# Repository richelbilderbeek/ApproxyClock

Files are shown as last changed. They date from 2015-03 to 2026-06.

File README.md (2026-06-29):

# Approxyclock

<!-- markdownlint-disable MD013 --><!-- Table rows must be put on one line, hence 80 chars is unavoidable -->






<!-- markdownlint-enable MD013 -->

[Go to our nicely rendered website](https://richelbilderbeek.github.io/approxyclock/).

- [Contributing](docs/CONTRIBUTING.md)

## Files used by continuous integration scripts

<!-- markdownlint-disable MD013 --><!-- Table rows must be put on one line, hence 80 chars is unavoidable -->

Filename                                    |Descriptions
--------------------------------------------|--------------------------------------------------------------------------------------------------------------------------------------
[`mlc_config.json`](mlc_config.json)        |Configuration of the link checker, use `markdown-link-check --config mlc_config.json --quiet docs/**/*.md` to do link checking locally
[`.markdownlint.jsonc`](.markdownlint.jsonc)|Configuration of the Markdown linter, use `markdownlint "**/*.md"` to do markdown linting locally. The name of this file is a default name.
[`.markdownlintignore`](.markdownlintignore)|Files ignored by the Markdown linter, use `markdownlint "**/*.md"` to do markdown linting locally. The name of this file is a default name.

<!-- markdownlint-enable MD013 -->

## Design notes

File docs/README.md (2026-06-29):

# Approxyclock

The Approxyclock is
[one of my machines](https://github.com/richelbilderbeek/Machines)
that uses (the programmable chip of an) Arduino.

It is a clock that gives the correct time, but humans can only approximately estimate it.

- [Photos](photos/README.md)
- [Parts list](parts_list/README.md)
- [Code](src/README.md)
- [Schematic](schematic/README.md)
- [Casing](casing/README.md)
- [FAQ](faq.md)

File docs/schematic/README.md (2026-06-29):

# Schematics

There are two schematics:

## Approxyclock connected to an Arduino

- [Arduino version](approxyclock_with_arduino.fzz)

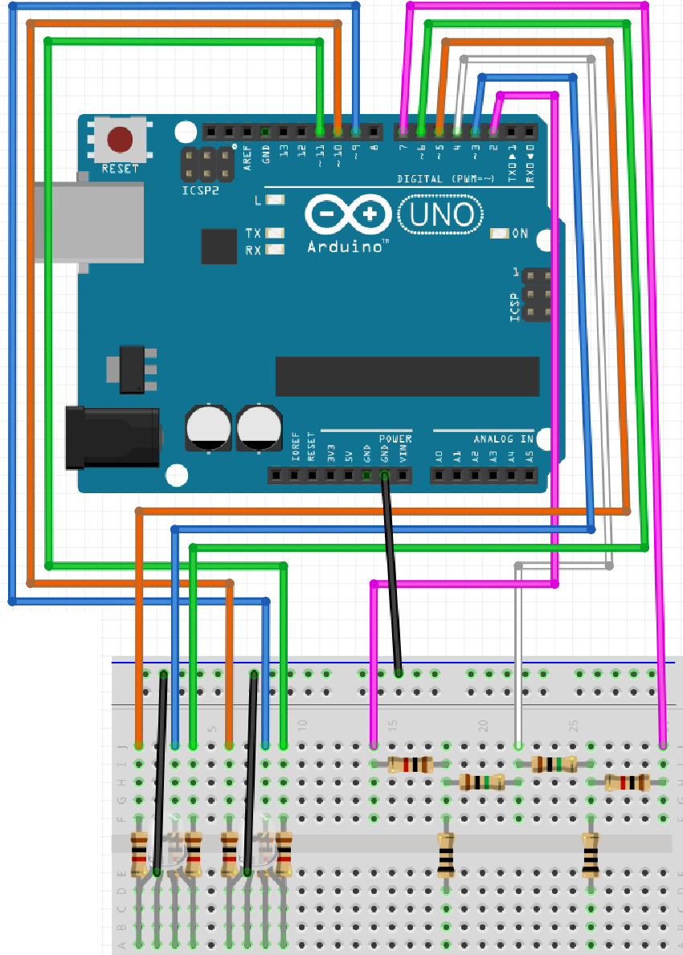
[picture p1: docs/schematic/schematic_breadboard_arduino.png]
Approxyclock connected to an Arduino


## Approxyclock connected to an ATmega328P chip

- [ATmega328P version](approxyclock.fzz)

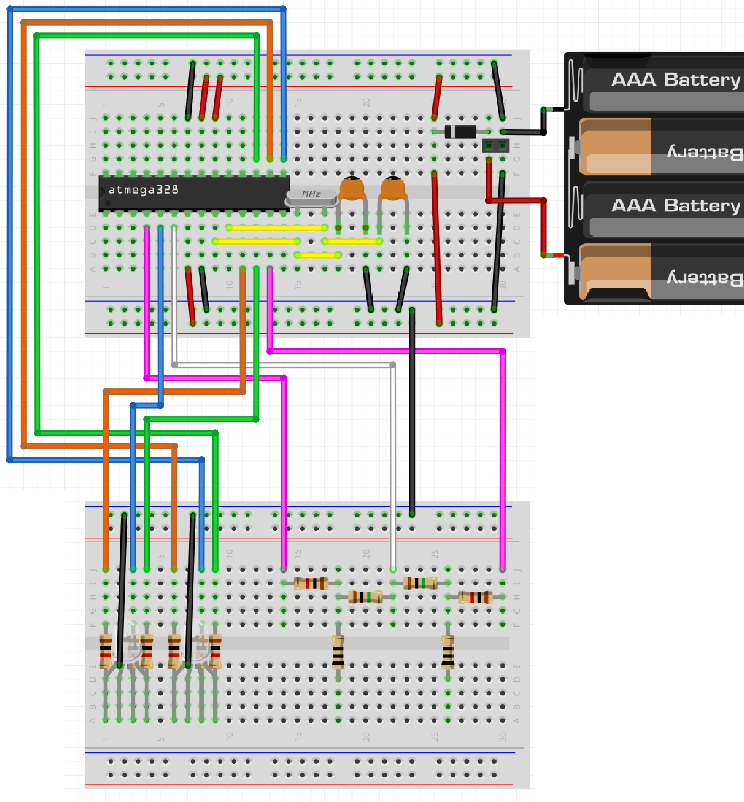
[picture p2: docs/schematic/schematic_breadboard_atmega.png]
Approxyclock connected to an ATmega328P chip


Build the schematic as such,
using the chip with The Minimal Pi Clock
program on it.

??? question "In which orientation must I have the chip?"

    The notch of the chip must be at the left:

    The notch of the chip must be at the left

    > The notch of the chip must be at the left.

??? question "Can you show the wiring of the chip as a table?"

    Yes.

    Here is an equivalent table:

    Pin  |1  |2  |3  |4  |5  |6  |7  |8  |9  |10 |11 |12 |13 |14
    -----|---|---|---|---|---|---|---|---|---|---|---|---|---|---
    Upper|.  |.  |.  |.  |.  |.  |GND|5V |5V |.  |.  |G2 |R2 |B2
    Lower|.  |.  |.  |G1 |R1 |B1 |5V |GND|X1 |X2 |.  |.  |.  |.

    - `GND`: to ground
    - `5V`: to 5 volt
    - `X1`: to a capacitor and crystal
    - `X2`: to (another) capacitor and (the same) crystal
    - `R1`: red LED of first RGB LED
    - `G1`: green LED of first RGB LED
    - `B1`: blue LED of first RGB LED
    - `R2`: red LED of second RGB LED
    - `G2`: green LED of second RGB LED
    - `B2`: blue LED of second RGB LED

??? question "What does '5 Volts in any way' mean?"

    Where the schematic states '5 Volts in any way',
    this means any reasonable way to provide 5 volts
    for the machine.

    In this example, a USB-B female is shown,
    but any USB connector can be used.

??? question "Can I use other electric potenials than 5V?"

    Yes.

    The range of the chip is wider than 5 volts.

Upon powering this, one LED will be dark, but increasingly red every second.
The other LED will be red.

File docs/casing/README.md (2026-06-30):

# Casing

- OpenSCAD file: [`casing.scad`](casing.scad)

I designed the casing in OpenSCAD:

<!--

I used two OpenSCAD libraries:

- [BOSL2](https://github.com/BelfrySCAD/BOSL2): to be able to use
  structures
- [text_on_OpenSCAD](https://github.com/brodykenrick/text_on_OpenSCAD):
  for the text on the machine

-->

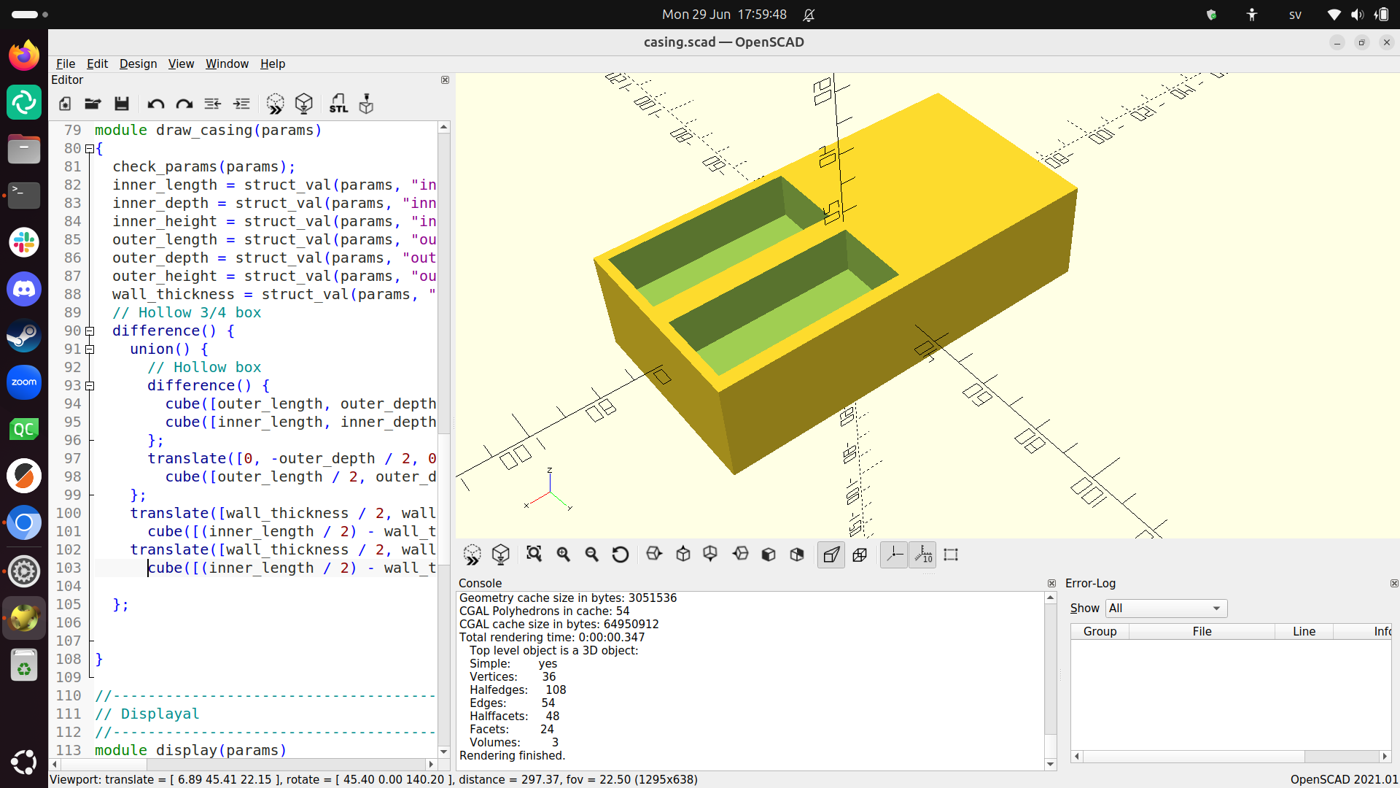
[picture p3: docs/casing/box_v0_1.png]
Current casing


## Box

First, I decided to go with the classical design I used before,
using a box

- OpenSCAD file: [`box.scad`](box.scad)

Approxyclock, box design v0.1

> box design v0.1

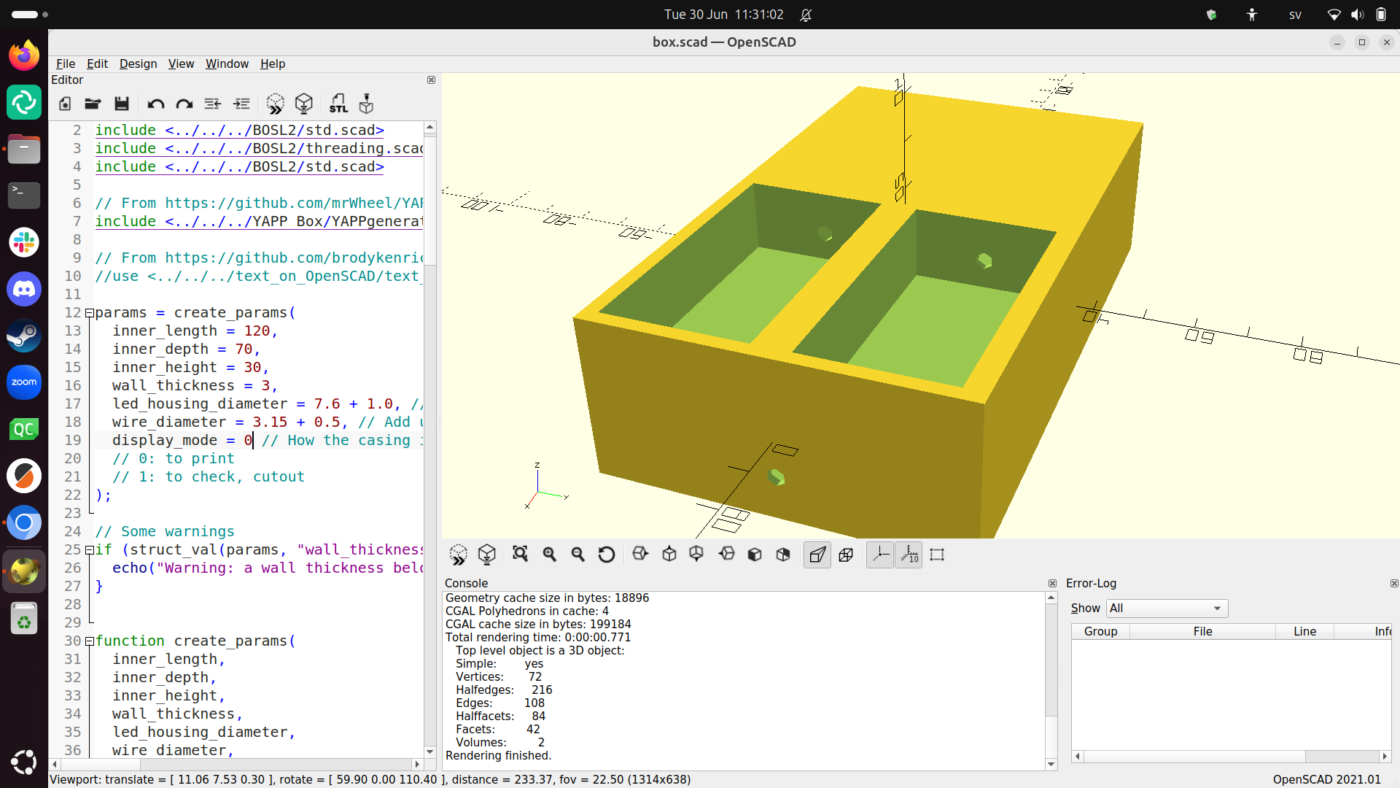
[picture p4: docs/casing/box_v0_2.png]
Approxyclock, box design v0.2


> box design v0.2

Then I realized, that with 3 printing, there is no need to stick to boxes:
I can be more free in the design of my casings: I can make the case round
and use a screw to connect the two parts.

I decided to call my new design the 'Lipstick' design.

## Lipstick

I started with the design of
[The Minimal Pi Clock](https://richelbilderbeek.github.io/minimal_pi_clock/)
and made its spherical design more egg shaped:

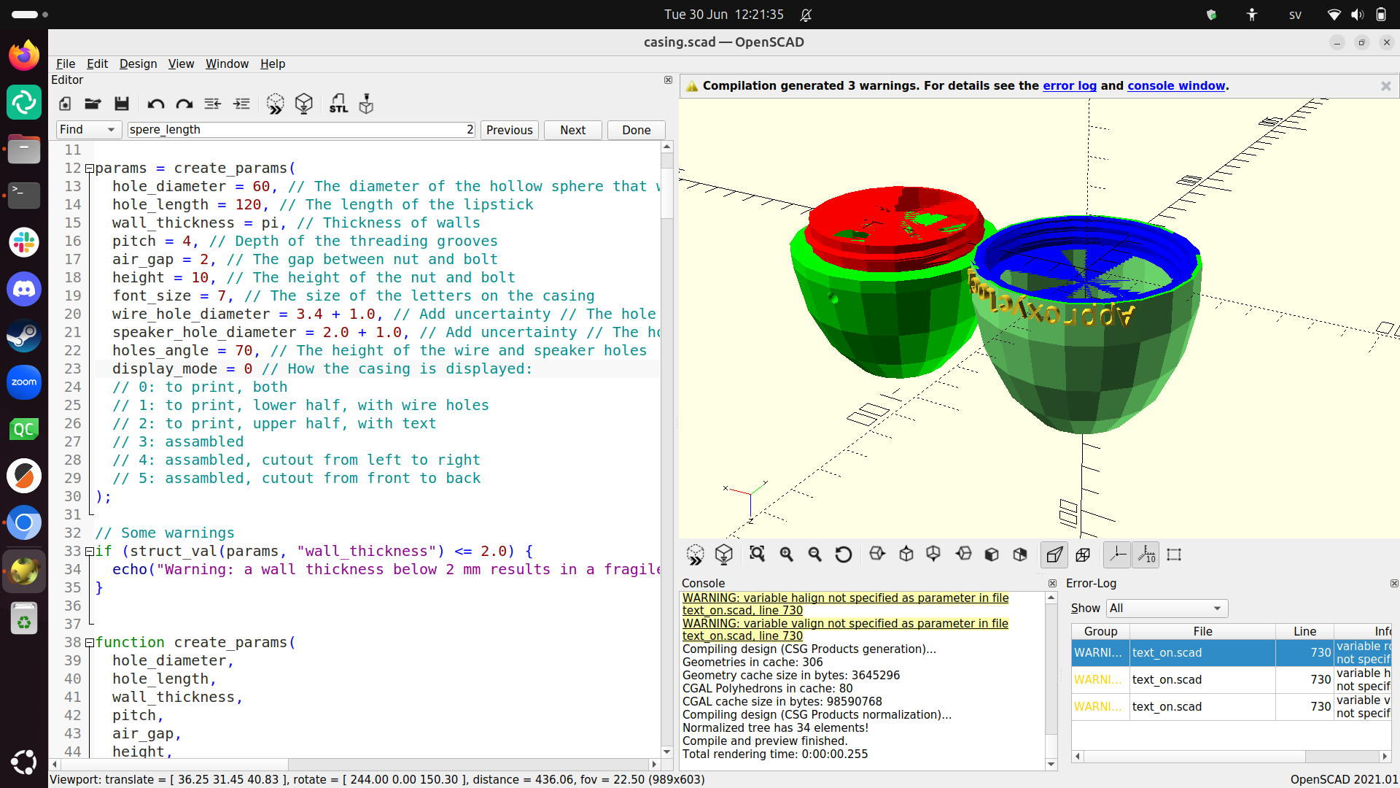
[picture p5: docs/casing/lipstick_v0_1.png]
Approxyclock, lipstick design v0.1


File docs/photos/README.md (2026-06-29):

# Photos

Ordered from new to old

## 2015-04-08: Start with PCB

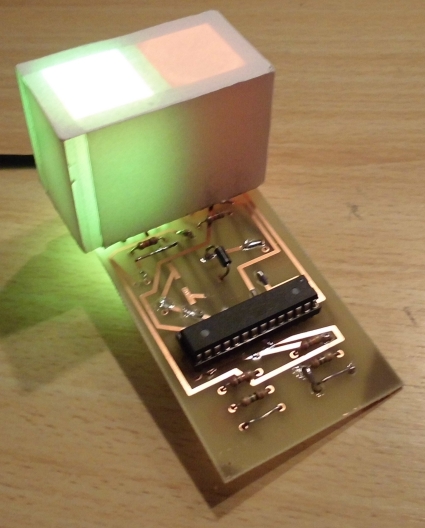
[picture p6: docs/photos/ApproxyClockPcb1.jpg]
ApproxyClock PCB 2015-04-08


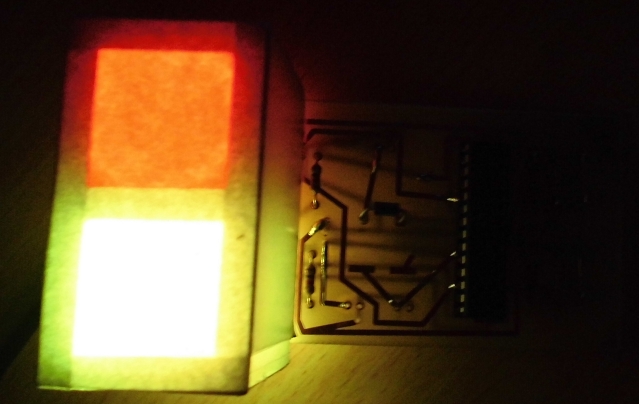
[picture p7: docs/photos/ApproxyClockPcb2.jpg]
ApproxyClock PCB 2015-04-08


## 2015-04-06: Wrapped a paper casing around it

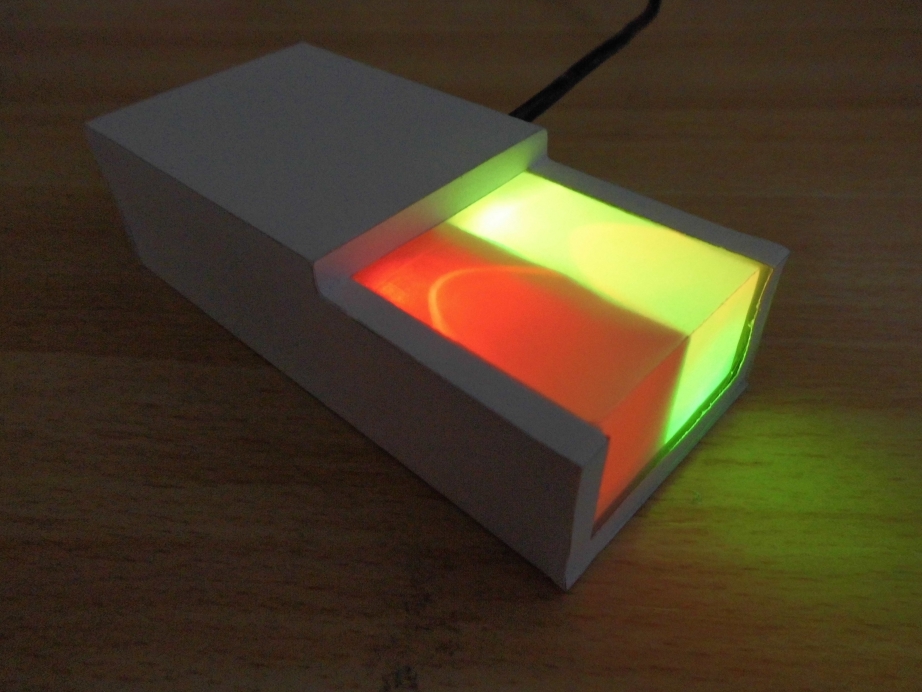
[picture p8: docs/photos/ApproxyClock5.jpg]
ApproxyClock 2015-04-06


## 2015-04-06: Added an extra cut-out

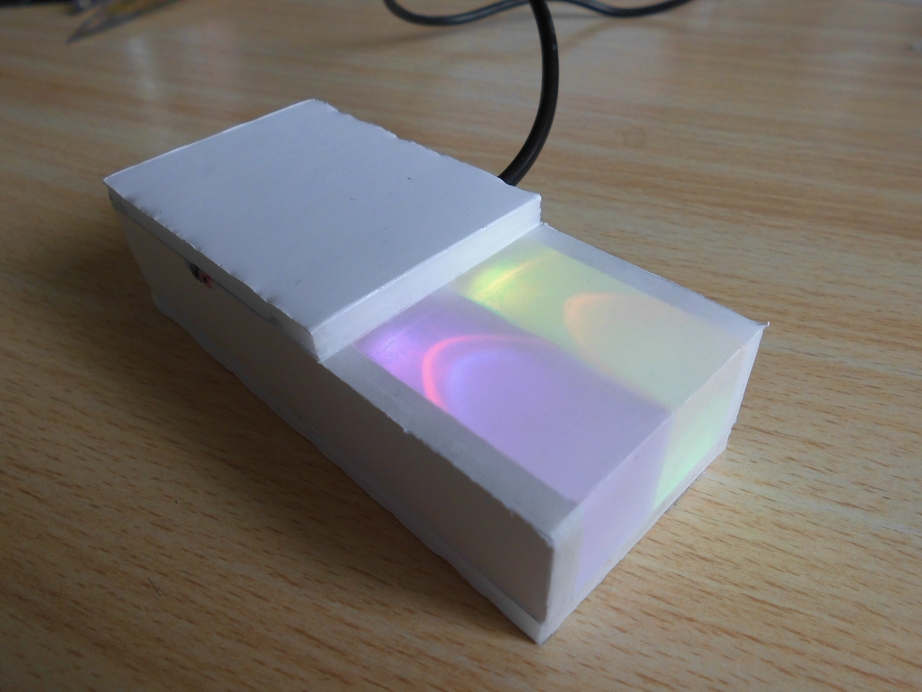
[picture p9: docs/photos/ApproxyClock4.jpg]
ApproxyClock 2015-04-06


## 2015-03-29: Assembled version

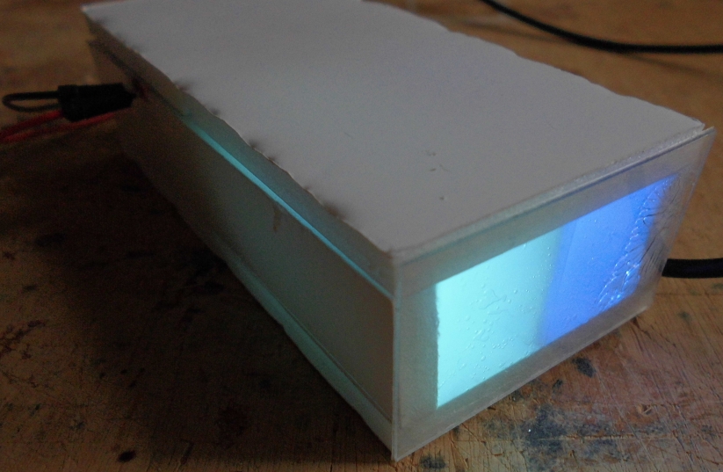
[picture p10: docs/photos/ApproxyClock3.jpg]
ApproxyClock 2015-03-29


## 2015-03-29: Peek into inside before assemblage

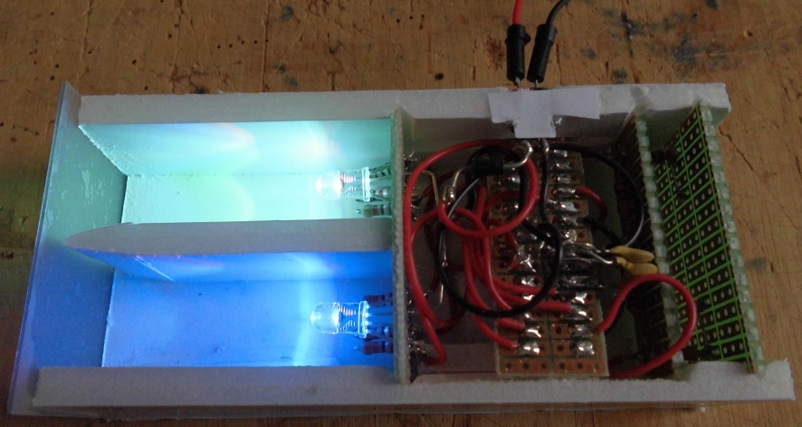
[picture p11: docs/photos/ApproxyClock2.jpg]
ApproxyClock 2015-03-29

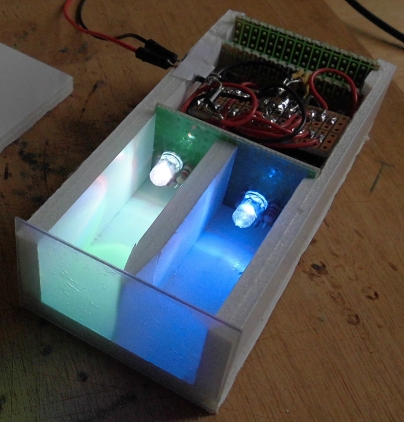
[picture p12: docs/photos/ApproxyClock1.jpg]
ApproxyClock 2015-03-29


## 2015-03-22: Prototype 3: Added touch sensors

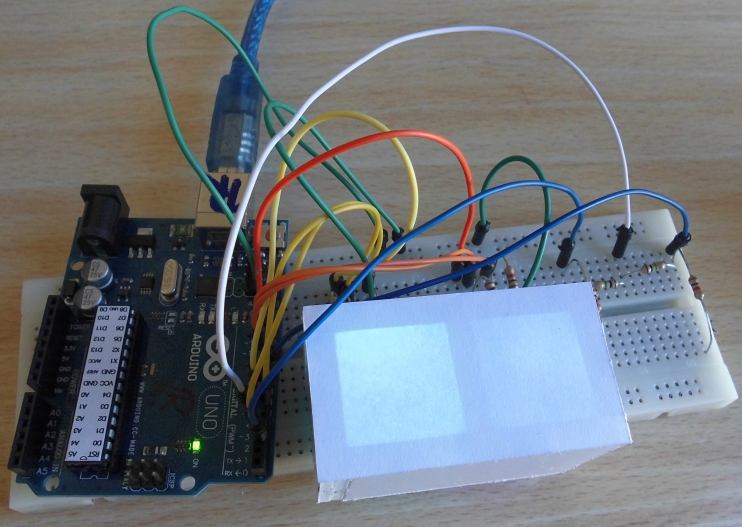
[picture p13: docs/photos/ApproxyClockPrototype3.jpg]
ApproxyClock prototype for 2015-03-22


## 2015-03-22: Prototype 2: Added rainbow time

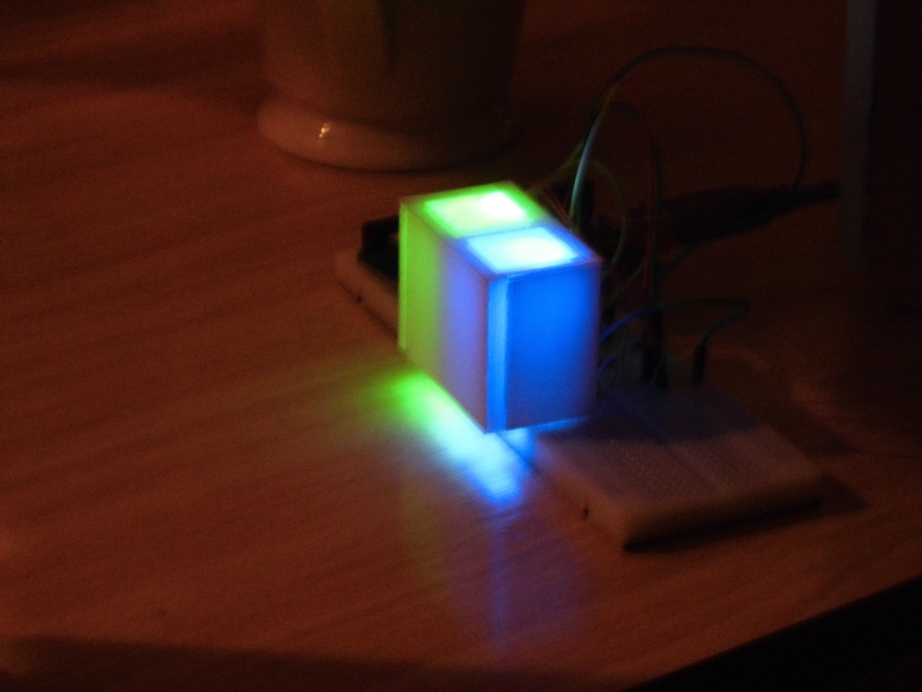
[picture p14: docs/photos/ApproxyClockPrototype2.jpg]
ApproxyClock prototype for 2015-03-22


## 2015-03-21: Prototype 1

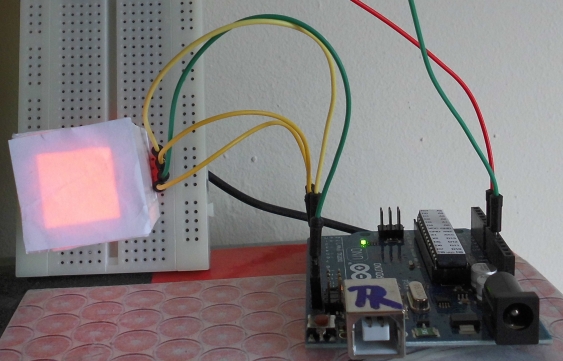
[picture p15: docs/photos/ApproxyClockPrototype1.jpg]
ApproxyClock prototype for 2015-03-21


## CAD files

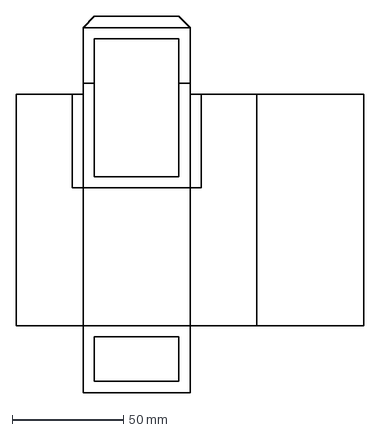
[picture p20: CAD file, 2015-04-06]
docs/casings_history/approxyclock_paper_casing.dxf
156.0 x 169.0 mm

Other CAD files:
docs/casing/box.scad
docs/casing/casing.scad

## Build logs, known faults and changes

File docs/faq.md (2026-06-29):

# Frequently Asked Questions

## How to read the time?

The time is shown in two different modes:

- Classic mode
- Rainbow mode

Classic mode displays the seconds in red, minutes in green, and hours in blue.

- 00:00:00: black
- 00:00:59: full red
- 00:59:00: full green
- 23:00:00: full blue
- 00:59:59: full yellow
- 23:59:00: full cyan
- 23:00:59: full magenta
- 23:59:59: full white

Rainbow mode displays the time according to the colors of the rainbow:

- 00:00: red
- 04:00: yellow
- 08:00: green
- 12:00: cyan
- 16:00: blue
- 20:00: magenta

## Can the ApproxyClock be powered by USB?

Yes. Set `use_usb_for_power` to `true`, which is the case by default.
If this is not the case, the capacitive sensors will work slowly.

## Can the ApproxyClock be powered by a 5V DC adapter?

Yes. Set `use_usb_for_power` to `true`, which is the case by default.
If this is not the case, the capacitive sensors will work slowly.

## Can the ApproxyClock be powered by 4x AAA batteries?

Yes. Set `use_usb_for_power` to `false`.
If this is not the case, the capacitive sensors will not work.

## How expensive is the ApproxyClock?

About ten euros

## Can I make an ApproxyClock myself?

Yes, it is rather easy. All schematics and code are on this GitHub.

## Will you make an ApproxyClock for me?

No. But I can give you two options:

- I can help you build one
- I can find people that like to build one

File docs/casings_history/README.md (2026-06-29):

# Casing's history

Here is the history of [the casing](README.md)
used in this machine.

## Paper

- FreeCAD file: [`approxyclock_paper_casing.dxf`](approxyclock_paper_casing.dxf)

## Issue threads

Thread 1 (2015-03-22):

Create BOM

richelbilderbeek, 2015-03-22:
Create a BOM:

* Arduino, bare bone kit:
 * 1x [Arduino Bare Bones kit](http://www.okaphone.com/artikel.asp?id=476081)
* Or Arduino, loose components (need to upload bootloader):
 * 2x [Capacitor, 47 pF  (22 pF would suffice)](http://www.okaphone.com/artikel.asp?id=478958)
 * 1x [Crystal  (Q16 MHZ HC 49/S), 16 MHz, capacity 32 pF, resonance resistance 50 ohm](http://www.okaphone.com/artikel.asp?id=460438)
 * 1x [Atmega chip](http://www.okaphone.com/artikel.asp?id=468509)

Rest:
* 2x [RGB LED](http://www.okaphone.com/artikel.asp?id=467470)
* 8x 1000 Ohm (brown-black-red-gold) resistance
* 2x 1000000 Ohm (brown-black-green-gold) resistance

Power:
 * If you want to use batteries:
    * 1x [3 AA battery holder](http://www.okaphone.com/artikel.asp?id=1366)
    * 1x [Battery snap clip](http://www.okaphone.com/artikel.asp?id=435836)
 * If you want to use an adapter:
    * 1x 5V DC adapter

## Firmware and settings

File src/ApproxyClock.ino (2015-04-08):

/*

  ApproxyClock with RGB LEDs
  (C) 2015 Richel Bilderbeek

2015-03-21: v.1.0: Initial version
2015-03-22: v.1.1: use of Time library
2015-03-22: v.1.2: added parallel display of rainbow format
2015-03-22: v.1.3: can set the (approximate) time using capacitive sensors
2015-03-22: v.1.4: show rainbow time while setting the clock
2015-03-22: v.1.5: bugfix in rainbow time
2015-04-01: v.1.6: capacitive sensor threshold is changed according to use of battery or USB/adapter

Original RGB LEDs:
    ___
   /   \
  |     |
  +-+-+-+
  | | | |
  | | | |
  | | |
    |
    
  1 2 3 4

1: Blue, connect with resistance of 1000 (brown-black-red-gold) to Arduino pin 3 (note: must be a PWM pin)
2: GND
3: Red, connect with resistance of 1000 (brown-black-red-gold) to Arduino pin 5 (note: must be a PWM pin)
4: Green, connect with resistance of 2200 (red-red-red-gold) to Arduino pin 6 (note: must be a PWM pin)

Rainbow RGB LEDs:
    ___
   /   \
  |     |
  +-+-+-+
  | | | |
  | | | |
  | | |
    |
    
  1 2 3 4

1: Blue, connect with resistance of 1000 (brown-black-red-gold) to Arduino pin 9 (note: must be a PWM pin)
2: GND
3: Red, connect with resistance of 1000 (brown-black-red-gold) to Arduino pin 10 (note: must be a PWM pin)
4: Green, connect with resistance of 2200 (red-red-red-gold) to Arduino pin 11 (note: must be a PWM pin)

Left capacitive sensor:

       +--------+     +--------+  
   2 --+   RS   +--+--+   RH   |-- 4
       +--------+  |  +--------+
                   |
                   X

  2: sensor pin
  4: helper pin
  RH: 'resistance helper', resistance of at least 1 Mega-Ohm (brown-black-green-gold)
  RS: 'resistance sensor', resistance of 1 kOhm (brown-black-red-gold)
  X: place to touch wire

Right capacitive sensor:

       +--------+     +--------+  
   7 --+   RS   +--+--+   RH   |-- 4
       +--------+  |  +--------+
                   |
                   X

  7: sensor pin
  4: helper pin
  RH: 'resistance helper', resistance of at least 1 Mega-Ohm (brown-black-green-gold)
  RS: 'resistance sensor', resistance of 1 kOhm (brown-black-red-gold)
  X: place to touch wire

*/

//if NDEBUG is #defined, this is a release version
#define NDEBUG

#include <CapacitiveSensor.h>
#include <Time.h>

//User setup

//If you use an USB cable or adapter, set use_usb_for_power to true
//If you use 4x AAA batteries, set use_usb_for_power to false
const bool use_usb_for_power = false;

//End of user setup

const int blue_original_pin = 3;
const int red_original_pin = 5;
const int green_original_pin = 6;

const int blue_rainbow_pin = 9;
const int red_rainbow_pin = 10;
const int green_rainbow_pin = 11;

/* When using the PCB print:
const int blue_original_pin  = 6;
const int red_original_pin   = 3;
const int green_original_pin = 5;

const int blue_rainbow_pin  = 11;
const int red_rainbow_pin   = 9;
const int green_rainbow_pin = 10;
*/

const int pin_sensor1 =  2;
const int pin_helper1 =  4;
CapacitiveSensor sensor1 
  = CapacitiveSensor(pin_helper1,pin_sensor1);        

const int pin_sensor2 =  7;
const int pin_helper2 =  4;
CapacitiveSensor sensor2 
  = CapacitiveSensor(pin_helper2,pin_sensor2);        


const int error_pin = 13;

//Threshold for capacitive sensor, which determines the sensitivity of the sensors
// - too low: the program will think more often there is a touch, possibly even when you do not touch
// - too high: the program will think less often there is a touch, possibly even when you do touch
//Some guidelines I use:
// - Using an adapter or USB: 200
// - Using 4x 1.5 AAA battery: 50
const int threshold_usb = 200;
const int threshold_batteries = 50;

void OnError(const String& error_message)

{
  Serial.print("ERROR: ");  
  Serial.println(error_message);  
  while (1)
  {
    //Blink LED
    digitalWrite(error_pin,!digitalRead(error_pin));
    //Write to serial
    delay(1000);
  }
}

void TestTime()
{
  //  setTime(hours, minutes, seconds, days, months, years);
  const int hours = 11;
  const int minutes = 22;
  const int seconds = 33;
  const int days = 0;
  const int months = 0;
  const int years = 0;
  setTime(hours, minutes, seconds, days, months, years);
  if (hour() != hours) { OnError("TestTime #1"); }
  if (minute() != minutes) { OnError("TestTime #1"); }
  if (second() != seconds) { OnError("TestTime #1"); }
  setTime(0,0,0,0,0,0);
}

void setup()
{
  pinMode(red_original_pin,OUTPUT);
  pinMode(green_original_pin,OUTPUT);
  pinMode(blue_original_pin,OUTPUT);
  pinMode(red_rainbow_pin,OUTPUT);
  pinMode(green_rainbow_pin,OUTPUT);
  pinMode(blue_rainbow_pin,OUTPUT);
  pinMode(error_pin,OUTPUT);
  Serial.begin(9600); //Cannot be used: chip is used stand-alone
  #ifndef NDEBUG
  Serial.println("ApproxyClock v. 1.5 (debug version)");
  #else //NDEBUG
  Serial.println("ApproxyClock v. 1.5 (release version)");
  #endif //NDEBUG
  TestTime();
}

//0 = 00 : none pressed
//1 = 01 : right pressed
//2 = 10 : left pressed
//3 = 11 : both pressed
const int state_no_sensor_pressed    = 0; //00
const int state_right_sensor_pressed = 1; //01
const int state_left_sensor_pressed  = 2; //10
const int state_both_sensors_pressed = 3; //11

///Obtain the current state of both capacitive sensors
int GetSensors()
{
  //The higher 'samples' is set, the more accurate the sensors measure
  const int samples = 30;
  //Measure the capacitive sensors
  const int r1 = sensor1.capacitiveSensor(samples);
  const int r2 = sensor2.capacitiveSensor(samples);
  //The threshold value, which determines the sensitivity of the sensors
  // - too low: the program will think more often there is a touch, possibly even when you do not touch
  // - too high: the program will think less often there is a touch, possibly even when you do touch
  //Some guidelines I use:
  // - Using an adapter or USB: 200
  // - Using 4x 1.5 AAA battery: 50
  const int threshold = use_usb_for_power ? threshold_usb : threshold_batteries;
  const int state =  (r1 >= threshold ? 2 : 0) + (r2 >= threshold ? 1 : 0);
  return state;
}

/// User can choose to set the hours
/// - left sensor: cancel
/// - right sensor: set hours
void SetHours()
{
  Serial.println("Setting hours");
  int h = hour();
  bool accept = false; //Accept editing the hours
  while (1)
  {
    //The line below is commented out, because the user must first accept to edit it
    //ShowTimeOriginal(0,0,h); //secs, mins, hours
    const int sensor_state = GetSensors();
    if (sensor_state == state_left_sensor_pressed)
    {
      //  setTime(hours, minutes, seconds, days, months, years);
      setTime(h,minute(),second(),0,0,0);
      break; 
    }
    if (sensor_state == state_right_sensor_pressed)
    {
      if (accept) { h = (h + 1) % 24; }
      else { accept = true; }
    }
    //This line is put here, because the user must first accept to edit the time
    ShowTimeOriginal(0,0,h); //secs, mins, hours
    ShowTimeRainbow(second(),minute(),h); //secs, mins, hours
    delay(100);
  }
  #ifndef NDEBUG
  if (h <  0) { OnError("h <  0, h = " + String(h)); }
  if (h > 23) { OnError("h > 23, h = " + String(h)); }
  #endif // NDEBUG
}

/// User can choose to set the minutes
/// - left sensor: cancel
/// - right sensor: set minutes
void SetMinutes()
{
  Serial.println("Setting minutes");
  int m = minute();
  bool accept = false; //Accept editing the minutes
  while (1)
  {
    ShowTimeOriginal(0,m,0); //secs, mins, hours
    ShowTimeRainbow(second(),m,hour()); //secs, mins, hours
    const int sensor_state = GetSensors();
    if (sensor_state == state_left_sensor_pressed)
    {
      //  setTime(hours, minutes, seconds, days, months, years);
      setTime(hour(),m,second(),0,0,0);
      break; 
    }
    if (sensor_state == state_right_sensor_pressed)
    {
      if (accept) { m = (m + 1) % 60; }
      else { accept = true; }
    }
    delay(100);
  }
  #ifndef NDEBUG
  if (m <  0) { OnError("m <  0, h = " + String(m)); }
  if (m > 59) { OnError("m > 59, h = " + String(m)); }
  #endif // NDEBUG
}

/// User can choose to set the seconds
/// - left sensor: cancel
/// - right sensor: set seconds
void SetSeconds()
{
  Serial.println("Setting seconds");
  int s = second();
  bool accept = false; //Accept editing the seconds
  while (1)
  {
    ShowTimeOriginal(s,0,0); //secs, mins, hours
    ShowTimeRainbow(s,minute(),hour()); //secs, mins, hours
    const int sensor_state = GetSensors();
    if (sensor_state == state_left_sensor_pressed)
    {
      //  setTime(hours, minutes, seconds, days, months, years);
      setTime(hour(),minute(),s,0,0,0);
      break; 
    }
    if (sensor_state == state_right_sensor_pressed)
    {
      if (accept) { s = (s + 1) % 60; }
      else { accept = true; }
    }
    delay(100);
  }
  #ifndef NDEBUG
  if (s <  0) { OnError("s <  0, h = " + String(s)); }
  if (s > 59) { OnError("s > 59, h = " + String(s)); }
  #endif // NDEBUG
}


/// User can choose to set the time
/// - left sensor: select hours, minutes, seconds, cancel
/// - right sensor: change hours, minutes, seconds
void SetTime()
{
  Serial.println("Setting time");
  //The user can choose to set the hours, make the hours blink
  while (1)
  {
    //Blink hours
    ShowTimeOriginal(0,0,23); //Secs, mins, hours
    delay(100);
    ShowTimeOriginal(0,0,0); //Secs, mins, hours
    delay(100);
    const int sensor_state = GetSensors();
    if (sensor_state == state_right_sensor_pressed)
    {
      SetHours();
      break;
    }
    if (sensor_state == state_left_sensor_pressed)
    {
      break; 
    }
  }  
  //The user can choose to set the minutes, make the minutes blink
  while (1)
  {
    //Blink minutes
    ShowTimeOriginal(0,59,0); //Secs, mins, hours
    delay(100);
    ShowTimeOriginal(0,0,0); //Secs, mins, hours
    delay(100);
    const int sensor_state = GetSensors();
    if (sensor_state == state_right_sensor_pressed)
    {
      SetMinutes();
      break;
    }
    if (sensor_state == state_left_sensor_pressed)
    {
      break; 
    }
  }  
  //The user can choose to set the seconds, make the seconds blink
  while (1)
  {
    //Blink second
    ShowTimeOriginal(59,0,0); //Secs, mins, hours
    delay(100);
    ShowTimeOriginal(0,0,0); //Secs, mins, hours
    delay(100);
    const int sensor_state = GetSensors();
    if (sensor_state == state_right_sensor_pressed)
    {
      SetSeconds();
      break;
    }
    if (sensor_state == state_left_sensor_pressed)
    {
      break; 
    }
  }  
}

void SetTimeFromSerial()
{
  //Serial.println("Start of SetTimeFromSerial");
  const int  h  = Serial.available() ? Serial.parseInt() : -1;
  delay(10);
  const char c1 = Serial.available() ? Serial.read() : '0';
  delay(10);
  const int  m  = Serial.available() ? Serial.parseInt() : -1;
  delay(10);
  const char c2 = Serial.available() ? Serial.read() : '0';
  delay(10);
  const int  s  = Serial.available() ? Serial.parseInt() : -1;
  delay(10);
  const String used = String(h) + String(c1) + String(m) + String(c2) + String(s);
  if (h == -1) 
  {
    Serial.println(String("No hours, use e.g. '12:34:56' (used '") + used + String("')"));
    return;
  }
  if (c1 == '0') 
  {
    Serial.println("No first seperator, use e.g. '12:34:56' (used '" + used + "')");
    return;
  }
  if (m == -1) 
  {
    Serial.println("No minutes, use e.g. '12:34:56' (used '" + used + "')");
    return;
  }
  if (c2 == '0') 
  {
    Serial.println("No second seperator, use e.g. '12:34:56'");
    return;
  }
  if (s == -1) 
  {
    Serial.println("No seconds, use e.g. '12:34:56'");
    return;
  }
  if (h < 0 || h > 23)
  {
    Serial.println("Hours must be in range [0,23]");
    return;
  }
  if (m < 0 || h > 59)
  {
    Serial.println("Minutes must be in range [0,59]");
    return;
  }
  if (s < 0 || s > 59)
  {
    Serial.println("Seconds must be in range [0,59]");
    return;
  }
  setTime(h,m,s,0,0,0); 
}

void loop() 
{
  int last_sec = -1; //The previous second, used to detect a change in time, to be sent to serial monitor
  while (1)
  {
    //Respond to touches
    const int sensors_state = GetSensors();
    if (sensors_state == state_left_sensor_pressed) { SetTime(); delay(100); }

    if (Serial.available())
    {
      delay(100);
      SetTimeFromSerial();  
    }
    //Show the time
    const int s = second();
    const int m = minute();
    const int h = hour();

    if (last_sec == s) 
    {
      continue;
    }

    last_sec = s;
    ShowTimeOriginal(s,m,h);
    ShowTimeRainbow(s,m,h);

    //if (sensors_state == state_right_sensor_pressed) 
    { 
      const String time_now = String(h) + ":" + String(m) + ":" + String(s);
      Serial.println(time_now);
      delay(100);
    }
  }
}

///Show the time on all RGB LEDs
void ShowTimeOriginal(const int secs, const int mins, const int hours)
{
  #ifndef NDEBUG
  if (hours <  0) { OnError("ShowTime: hours <  0, hours = " + String(hours)); }
  if (hours > 23) { OnError("ShowTime: hours > 23, hours = " + String(hours)); }
  if (mins <  0) { OnError("ShowTime: mins <  0, mins = " + String(mins)); }
  if (mins > 59) { OnError("ShowTime: mins > 59, mins = " + String(mins)); }
  if (secs <  0) { OnError("ShowTime: secs <  0, secs = " + String(secs)); }
  if (secs > 59) { OnError("ShowTime: secs > 59, secs = " + String(secs)); }
  #endif // NDEBUG
  const int max_brightness = 255;
  const int red_value   = map(secs,0,60,0,max_brightness);
  const int green_value = map(mins,0,60,0,max_brightness);
  const int blue_value  = map(hours,0,24,0,max_brightness);
  analogWrite(red_original_pin,red_value);
  analogWrite(green_original_pin,green_value);
  analogWrite(blue_original_pin,blue_value);
}

///Show the time on all RGB LEDs using rainbow format
// B     R     G     B 
// +     +     +     +
// |\   / \   / \   / 
// | \ /   \ /   \ /
// |  X     X     X
// | / \   / \   / \
// |/   \ /   \ /   \
// +-----+-----+-----+
// 0     0     1     2
// 0     8     6     4
void ShowTimeRainbow(const int secs, const int mins, const int hours)
{
  #ifndef NDEBUG
  if (hours <  0) { OnError("ShowTimeRainbow: hours <  0, hours = " + String(hours)); }
  if (hours > 23) { OnError("ShowTimeRainbow: hours > 23, hours = " + String(hours)); }
  if (mins <  0) { OnError("ShowTimeRainbow: mins <  0, mins = " + String(mins)); }
  if (mins > 59) { OnError("ShowTimeRainbow: mins > 59, mins = " + String(mins)); }
  if (secs <  0) { OnError("ShowTimeRainbow: secs <  0, secs = " + String(secs)); }
  if (secs > 59) { OnError("ShowTimeRainbow: secs > 59, secs = " + String(secs)); }
  #endif // NDEBUG
  int red_value = 0;
  int green_value = 0;
  int blue_value = 0;
  if (hours < 8)
  {
    const double f = static_cast<double>((hours*60) + mins) / (8 * 60);
    green_value = static_cast<int>(f * 255.0);
    red_value = 255 - red_value;    
  }
  else if (hours < 16)
  {
    const double f = static_cast<double>(((hours-8)*60) + mins) / (8 * 60);
    blue_value = static_cast<int>(f * 255.0);
    green_value = 255 - blue_value;    
  }
  else if (hours < 24)
  {
    const double f = static_cast<double>(((hours-16)*60) + mins) / (8 * 60);
    red_value = static_cast<int>(f * 255.0);
    blue_value = 255 - red_value;
  }
  
  analogWrite(red_rainbow_pin,red_value);
  analogWrite(green_rainbow_pin,green_value);
  analogWrite(blue_rainbow_pin,blue_value);
  #ifndef NDEBUG
  const String debug_str 
    = String("RGB:") + String(red_value) + "," + String(green_value) + "," + String(blue_value)
  ;
  Serial.println(debug_str);
  
  if (red_value   <   0) { OnError("ShowTimeRainbow: red_value <  0, hours = " + String(hours)); }
  if (red_value   > 255) { OnError("ShowTimeRainbow: red_value > 255, hours = " + String(hours)); }
  if (green_value <   0) { OnError("ShowTimeRainbow: green_value <  0, mins = " + String(mins)); }
  if (green_value > 255) { OnError("ShowTimeRainbow: green_value > 255, mins = " + String(mins)); }
  if (blue_value  <   0) { OnError("ShowTimeRainbow: blue_value <  0, secs = " + String(secs)); }
  if (blue_value  > 255) { OnError("ShowTimeRainbow: blue_value > 255, secs = " + String(secs)); }
  #endif // NDEBUG
}

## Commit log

2015-03-21 Added schematic and reset
    [ApproxyClock.fzz]
2015-03-22 Added rainbow
    [ApproxyClock.fzz]
2015-03-22 Added capacitive sensors, version 1.3
2015-03-22 Added rainbow time while setting time, version 1.4
    [ApproxyClock.fzz]
2015-03-22 Added PDF
    [ApproxyClock.fzz]
2015-03-22 Added multi-PCR routing, might abandon this again later
    [ApproxyClock.fzz]
2015-03-29 PCB fixed
    [ApproxyClock.fzz]
2015-04-01 Improved design and code (to allow batteries)
    [ApproxyClock.fzz]
2015-04-06 Added paper jacket
    [ApproxyClockPaperCasing.dxf]
2015-04-08 Added PCB picture, improved PCB
    [ApproxyClock.fzz]
2016-08-09 Added Fritzing without buttons
    [ApproxyClockWithoutButtons.fzz]
2016-08-09 40 x 35 mm, profesional etching
    [ApproxyClockWithoutButtons.fzz]
2022-09-13 Show PCB versions
2024-02-17 Add schematic with Arduino
    [ApproxyClockWithArduino.fzz]
2024-02-17 Add ground
    [ApproxyClockWithArduino.fzz]
2026-06-08 Use correct course name 'Connect and File Transfer'
    [ApproxyClock.fzz]
2026-06-08 Revert "Use correct course name 'Connect and File Transfer'"
    This reverts commit 4d553fdcd7c0f4cd50ffd17085478961541ea915.
    [ApproxyClock.fzz]
2026-06-27 Create MkDocs
    [ApproxyClock.fzz, ApproxyClockPaperCasing.dxf, ApproxyClockWithArduino.fzz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]
2026-06-29 Add casing history
    [approxyclock_paper_casing.dxf]
2026-06-30 Start with öipstick design
    [box.scad]
2026-06-30 Start of lipstick design
    [casing.scad]
